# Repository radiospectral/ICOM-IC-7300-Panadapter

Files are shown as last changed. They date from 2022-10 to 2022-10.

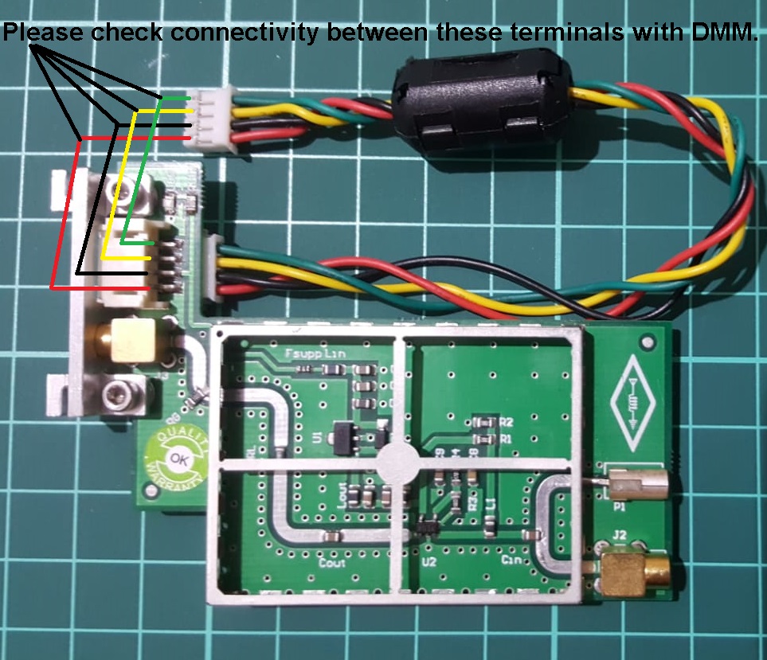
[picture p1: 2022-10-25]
tuner-cable-test.jpg

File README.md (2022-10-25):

# ICOM-IC-7300-Panadapter
RF out for ICOM-IC-7300

DISCLAIMER:
We are not responsible for any damage to your radio, and this is at your own risk operation.
If you don't have the basic electronic knowledge, we do not suggest you attempt to build this unit.

SCHEMATICS-ICOM-IC-7300-Panadapter.pdf : Schematic file.

gerber.zip                             : Zip archive, constains gerber files for the PCB manufacturing.
                                         You can use jlcpcb.com to order ready to use PCBs.

pcb-manufacture.png                    : PCB manufacturing settings for jlcpcb.com

BOM-ICOM-IC-7300-Panadapter.pdf        : Bill of materials.

fixture-7300.STEP                      : Fixture step file.  You may also print the part with 3D printer.

dc-test.png                            : Critical voltage points for testing. 

tuner-cable-test.jpg                   : One to one tuner cable connection and its test.

IMPORTANT:
The thickness of the PCB should be 1mm, and FR4 should be used as a material.

We encourage you to share this project with other ham radio operators to help them monitor the spectrum of the HF band
along with their SDR receivers. 

We hope our contribution helps the ham radio community build low cost and effective pan adapters for their rigs.

www.radiospectral.com

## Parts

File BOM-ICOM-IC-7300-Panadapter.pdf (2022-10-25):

Comment | Digi-Key_Purchase_URL | Digi-Key_Part_Number | Description | Designator | Quantity
10uF | https://www.digikey.com/short/zrnmq8tr | 1276-2891-6-ND | Cap Ceramic 10uF 25V X5R 10% SMD 0805 85Â°C Embossed T/R | C1, C4 | 2
100nF | https://www.digikey.com/short/004tpd78 | 445-5909-6-ND | Eia Case Size: 0805, Voltage: 50, Cap Value: 100000, Tol: +/-10%, ThC2, C5, C9, Cin, Cout | | 5
1nF | https://www.digikey.com/short/m75nn740 | 1276-1147-6-ND | CAP CER 1000PF 50V C0G/NP0 0805 | C3, C6 | 2
1uF | https://www.digikey.com/short/jqw4hfn2 | 445-5689-6-ND | 1ÂµF Â±10% 16V Ceramic Capacitor X7R 0805 _2012 Metric_ | C8 | 1
JST-PH-2mm-SMD-4p | https://www.digikey.com/short/qzwj0vr4 | 455-1751-6-ND | Digikey Number 455-1751-2-ND | CB, CT | 2
1N4148WTR | https://www.digikey.com/short/vd7dt7hp | 1655-1360-6-ND | Diode Standard 75V 250mA (DC) Surface Mount SOD-123 | D1 | 1
Fuse Thermal | https://www.digikey.com/short/993n53ph | 507-1818-6-ND | Thermal Fuse | Fsupp | 1
CONMCX002-ND | https://www.digikey.com/short/591fdwdd | CONMCX002-ND | RF Coaxial PCB Connector, MCX; Thru-Hole, Right-Angle Mount SockJ2, J3 | | 2
100uH | https://www.digikey.com/short/492zn5tj | 445-174997-6-ND | Inductor Decoupling Circuit Shielded Multi-Layer 100uH 20% 2MHz | L1 | 1
LED Green | https://www.digikey.com/short/n2p4z548 | 475-1410-6-ND | LED GREEN DIFFUSED 0805 SMD | LED | 1
2118731-2 | https://www.digikey.com/short/ftb3fjf0 | A126136-ND | Lid for rf-cage. | LID1 | 1
1uH | https://www.digikey.com/short/j7ppdvc9 | 445-6756-6-ND | 1ÂµH Shielded Multilayer Inductor 1.15A 60mOhm 0805 _2012 Metric Lin, Lout | | 2
TMP-S01X-B1 | N/A at DigiKey | N/A at Digikey please check TMP-S01X-B1 | TMP PC MOUNT JACK LOW PROFILE TYPE 20 DEGREE SOCKET | P1 | 1
20kOhm | https://www.digikey.com/short/280tdd43 | 311-20.0KCRDKR-ND | Res Thick Film 0805 20K Ohm 1% 0.125W_1/8W_ ?100ppm/?C Mold R1, R2 | | 2
560R | https://www.digikey.com/short/2dzn71p8 | 311-560CRDKR-ND | 560 Ohms Â±1% 0.125W, 1/8W Chip Resistor 0805 _2012 Metric_ MoisR3 | | 1
470R | https://www.digikey.com/short/vtr58020 | 311-470CRDKR-ND | 470 Ohms Â±1% 0.125W, 1/8W Chip Resistor 0805 _2012 Metric_ MoisR4 | | 1
1kOhm | https://www.digikey.com/short/m0b5dnjz | 311-1.00KCRDKR-ND | 0805/Case Surface Mount/Pkg 1/10-Watt 1k-Ohms 1pct-Tol Thick FilmRG | | 1
49R9 | https://www.digikey.com/short/rw1t5tv8 | 311-49.9CRDKR-ND | Res Thick Film 2.0 x 1.2 mm 49.9 Ohm 1% 0.125W_1/8W_ 100ppm/ | RL | 1
2.2k | https://www.digikey.com/short/0zcdv51n | 311-2.20KCRDKR-ND | 2.2 kOhms Â±1% 0.125W, 1/8W Chip Resistor 0805 _2012 Metric_ MoisRLED | | 1
2118732-2 | https://www.digikey.com/short/ncjw8rnw | A126160TR-ND | Rf cage. | Shield1 | 1
78L09 | https://www.digikey.com/short/37pr5f5w | 296-14331-6-ND | 9V@100mA Linear power supply IC. | U1 | 1
lmh6702 | https://www.digikey.com/short/zzb4r38j | LMH6702MF/NOPBDKR-ND | 1.7-GHz Ultra-Low Distortion Wideband Op Amp. | U2 | 1
SMA to MCX cable | https://www.digikey.com/short/81pf8f4j | 2210-LSA28-S1M1-S12-ND | SMA male to MCX male cable for SDR connection. | 1
Tuner cable housing | https://www.digikey.com/short/00jqhftf | 455-1164-ND | PH-4 to PH-4 one to one cable. | 2
Cable crimp tin | https://www.digikey.com/short/vjt83n8z | 455-1318-1-ND | Crimp tip for tuner cable | 8
Ferrite core | UF35-A | N/A | | 1

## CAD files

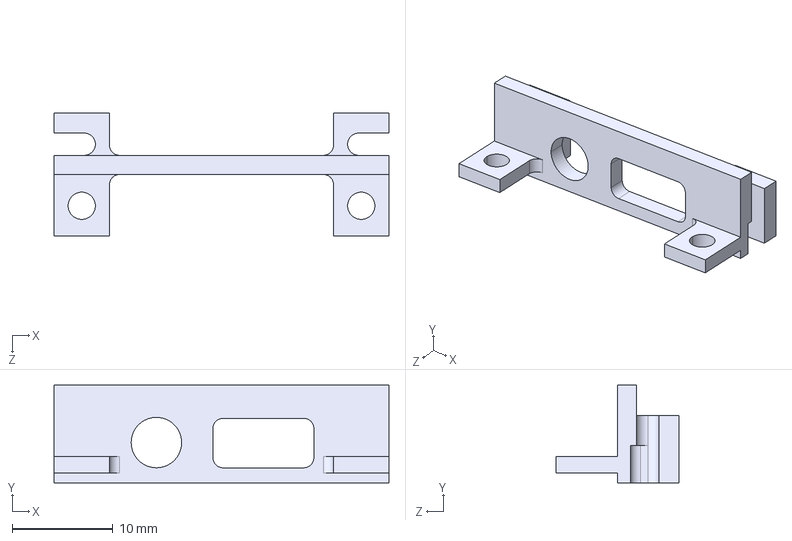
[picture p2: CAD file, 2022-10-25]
fixture-7300.step
33.2 x 9.70 x 12.2 mm

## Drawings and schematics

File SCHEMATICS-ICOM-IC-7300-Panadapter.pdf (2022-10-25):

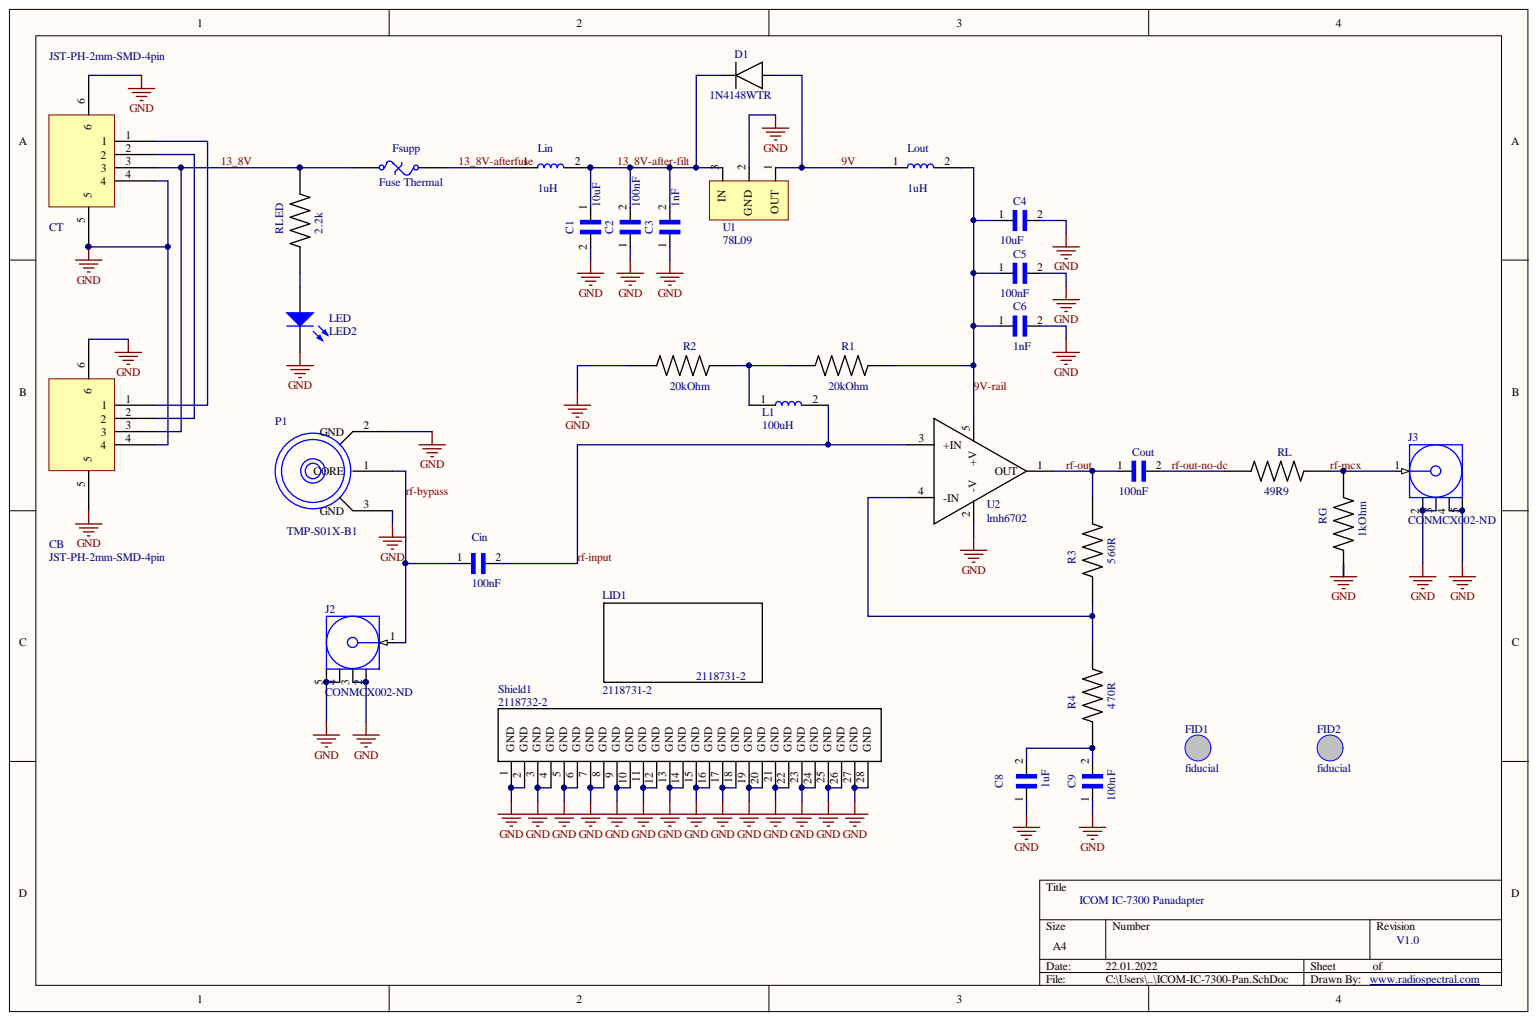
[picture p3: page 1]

GND GND GND GND GND GND GND

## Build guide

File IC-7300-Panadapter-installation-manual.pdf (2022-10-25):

### www.radiospectral.com ICOM IC-7300 PANADAPTER INSTALLATION GUIDE

DISCLAIMER: We are not responsible for any damage to your radio during installation. Please operate at your own risk.
This document has been prepared to help you to install ICOM IC-7300 Panadapter into your ICOM IC-7300 radio. This is solderless operation, therefore this installation does not require any equipment other than a phillips head screwdriver, and you can remove ICOM IC-7300 Panadapter from your radio at any time easily.

ICOM IC-7300 Panadapter shipped with following items as shown in Figure.1:
1- ICOM IC-7300 Panadapter.
2- TMP-MCX cable (to be connected to J1431).
3- 4 pin external tuner cable extension (to be connected to J331).
4- MCX to SMA cable.

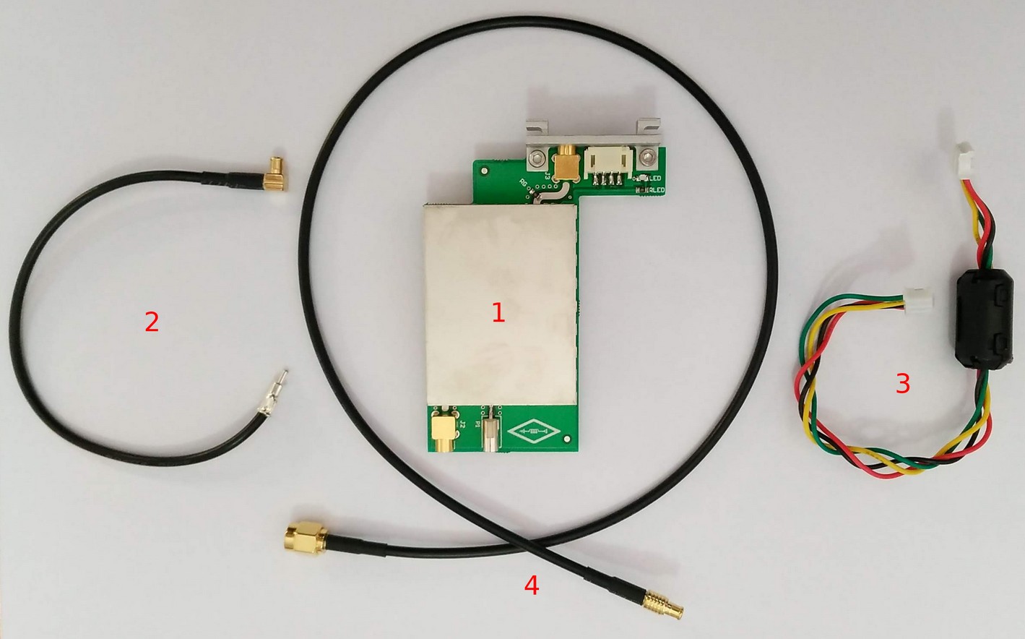
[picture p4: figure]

Figure.1 : ICOM IC-7300 Panadapter package items.

Installation Procedure
1- Plug item 3 (4 pins external tuner cable extension) to
ICOM IC-7300 Panadapter as in Figure.2.

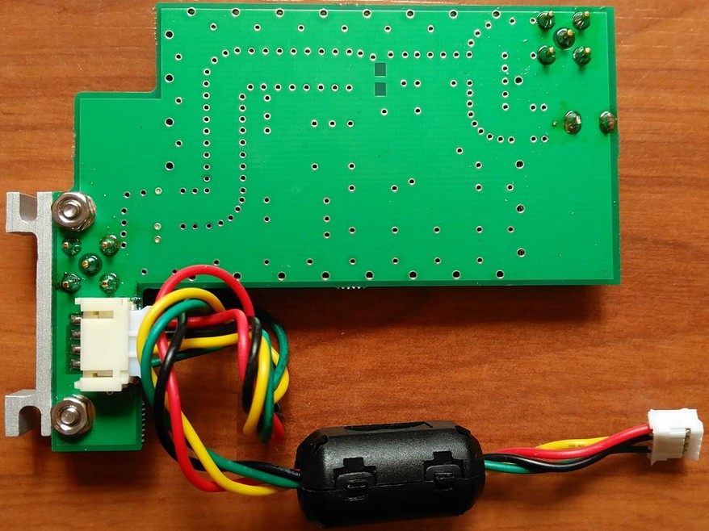
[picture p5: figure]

2- Open the top cover of the ICOM IC-7300 with a screw driver carefully.

3- Remove MOLEX/JST connector (in Figure.3) from your ICOM IC-7300.

4- Place ICOM IC-7300 Panadapter into the external tuner opening shown in
Figure.4.

5- Plug item 3 (4 pins external tuner cable extension) to J331
as shown in Figure.5. | Figure.2 : 4 pin tuner cable installation.

6- Plug TMP connector of the TX/RX line to ICOM IC-7300
Panadapter as shown in Figure.5.

7- Plug item 2 (TMP-MCX cable ) into J1431, and attach the MCX socket into the MCX port of ICOM IC-7300 Panadapter.

8- Plug item 4 (MCX to SMA cable) and external tuner cable into the RF/Tuner output of ICOM IC-7300 Panadapter.

9- Turn on your radio, and connect the SMA cable to your SDR
receiver. Make sure LED indicator of ICOM IC-7300
Panadapter is on. Once

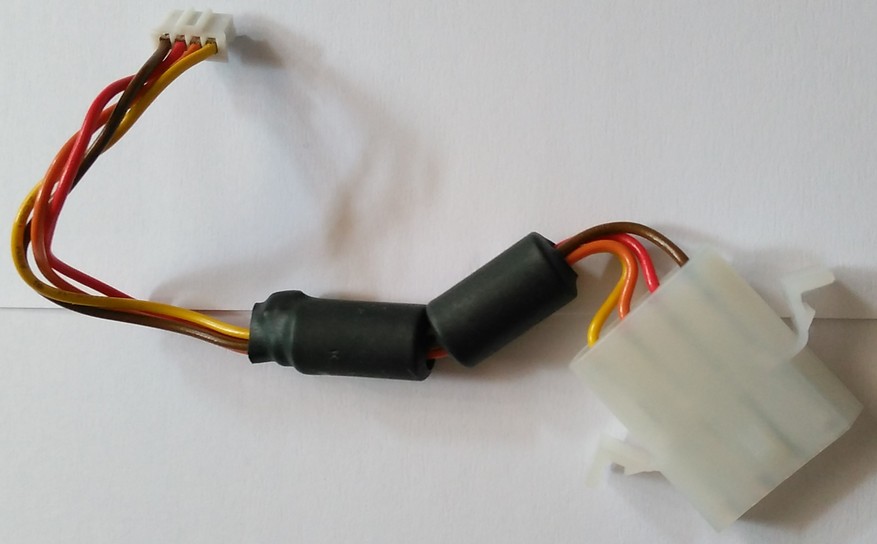
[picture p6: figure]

you test with your SDR receiver, you can close the top cover. | Figure.3 : MOLEX/JST external tuner cable.

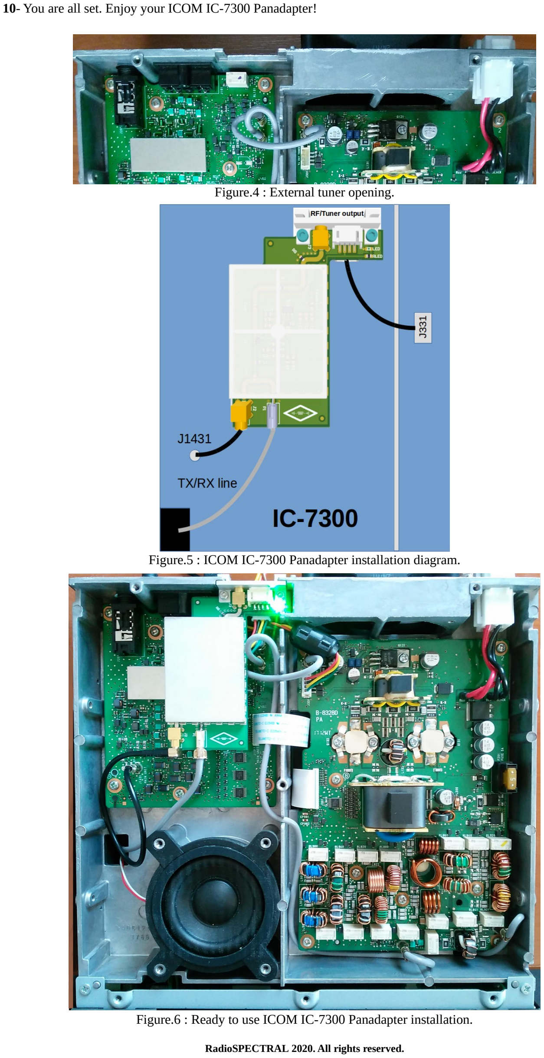
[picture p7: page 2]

10- You are all set. Enjoy your ICOM IC-7300 Panadapter!

Figure.4 : External tuner opening.

Figure.5 : ICOM IC-7300 Panadapter installation diagram.

Figure.6 : Ready to use ICOM IC-7300 Panadapter installation.

RadioSPECTRAL 2020. All rights reserved.

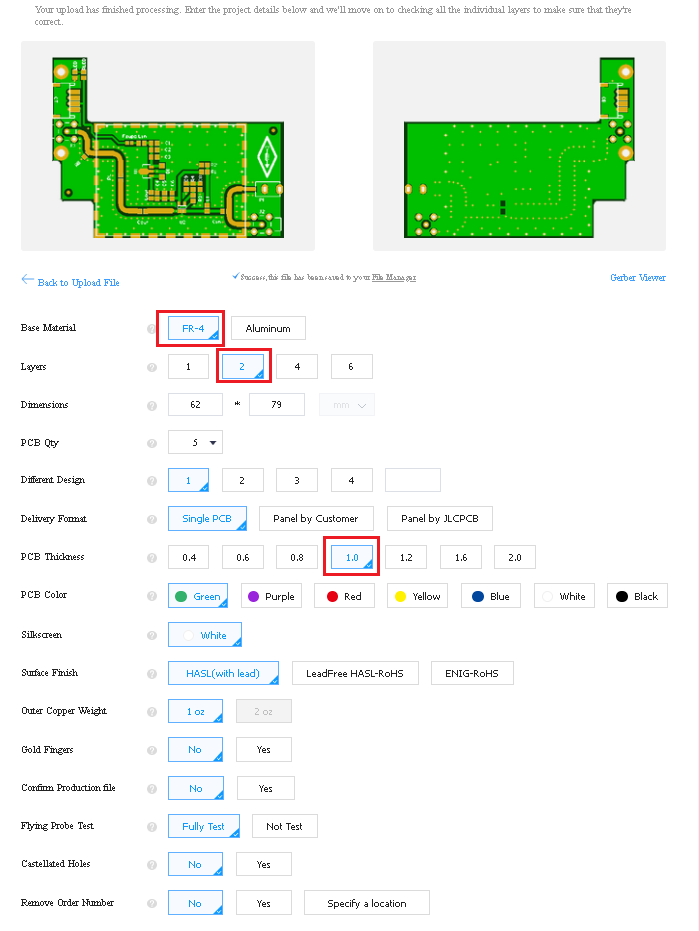
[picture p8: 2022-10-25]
pcb-manufacture.png

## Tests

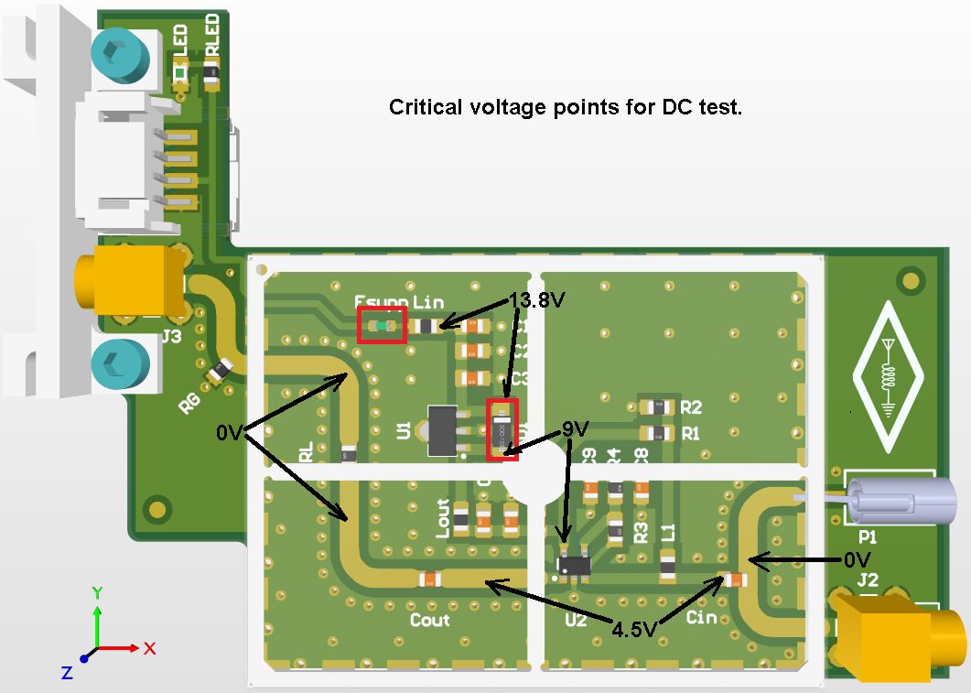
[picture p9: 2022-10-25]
dc-test.png
